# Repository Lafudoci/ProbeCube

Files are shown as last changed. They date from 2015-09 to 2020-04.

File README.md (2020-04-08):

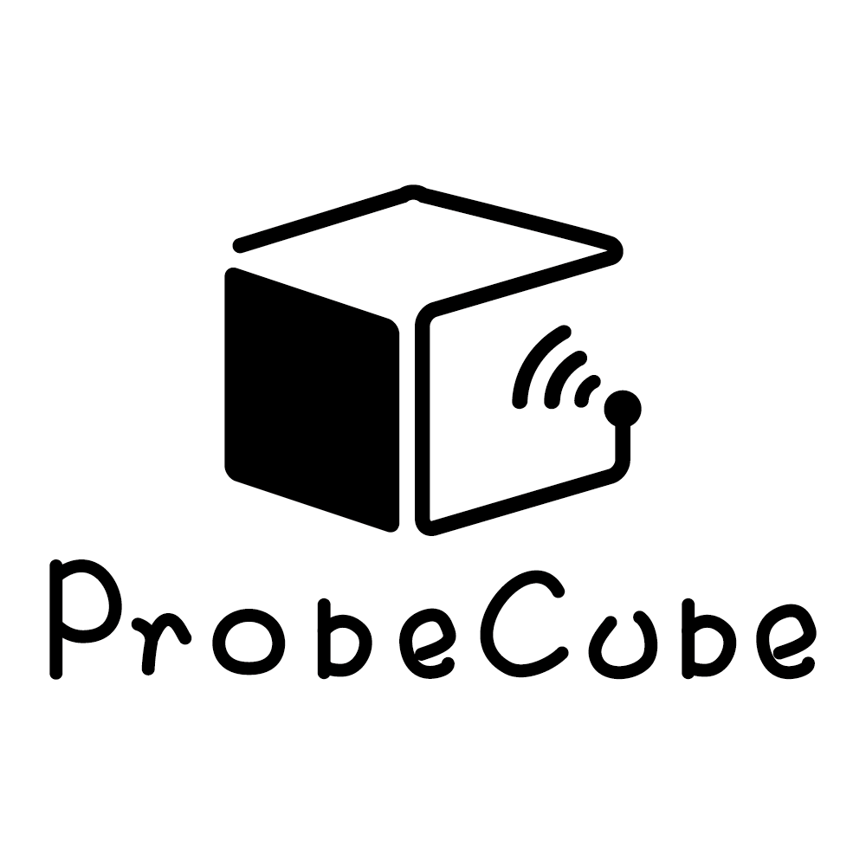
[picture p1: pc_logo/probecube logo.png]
 

## 專案簡介
ProbeCube是個基於開源硬體的物聯網專案，鼓勵大眾動手製作WiFi連網的機器來偵測空氣品質並組織共同的觀測地圖。

## 感測器開發方向原則
* 零件需容易取得
* 低組裝與操作門檻
* 相容於MIT開放原始碼授權

## 運作原理
空氣汙染 -> 感測器 -> Arduino(wifi) -> Thingspeak -> 觀測地圖

## 可相容的控制板
* Arduino NANO, UNO + Adafruit CC3000 wifi module
* Particle Photon

## 可相容的感測器
* 溫度/濕度 - DHT22
* 空氣中總揮發物質(VoCs) - FIGARO tgs2602
* 懸浮微粒PM2.5 - PMS3003(G3) 或 GP2Y1010AU0F
* 輻射劑量 - pockect gieger

## PCB設計附加規格
* 全腳位預留輸出排母
* I2C預留接座x2
* groove 預留接座x1

## 資料呈現方式
* 行動裝置: [Blynk app](http://www.blynk.cc/) (詳見範例)
* 網頁: Thingspeak, g0v零時空污觀測網 (詳見範例)

## 外殼
* 3D 列印外殼
* 自行挖洞加工收納盒 ( ex. 大創$39x2)

## 如何開始
1. 準備材料 (材料表)
2. 在PCB上焊接或使用麵包板連接各部元件組成ProbeCube
3. 註冊[Thingspeak](https://thingspeak.com/)帳號並設定上傳之頻道(channel)
4. 將程式碼依需要修改後編譯寫入ProbeCube
5. ProbeCube的資料將會上傳至Thingspeak
6. 到ProbeCube共同觀測地圖提交你的Thindspeak Channel ID分享資料(已併入g0v專案，請參考連結)

## 範例
* 麵包版接線示意

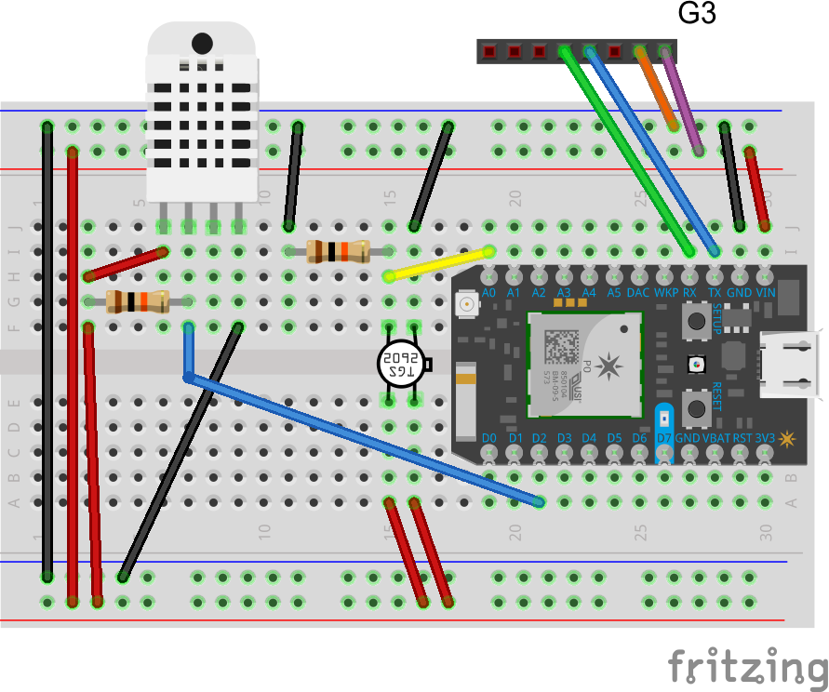
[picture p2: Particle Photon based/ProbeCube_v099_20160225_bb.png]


* 可洗PCB幫助縮小裝置體積

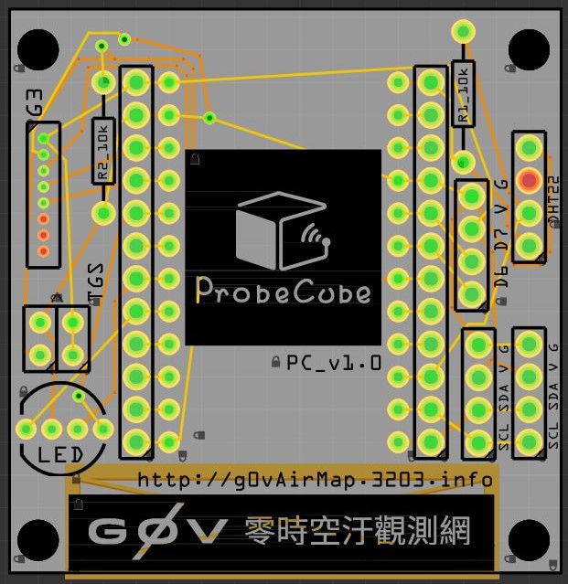
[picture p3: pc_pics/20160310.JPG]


* 由arduino uno為搭配已洗好PCB組裝後的ProbeCube  

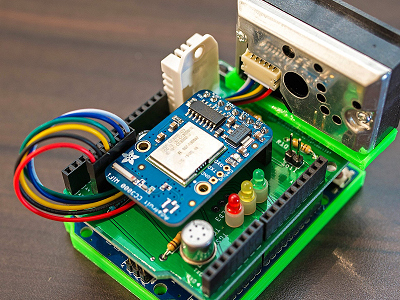
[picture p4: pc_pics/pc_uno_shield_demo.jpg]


* 用大創盒子挖洞加工成外殼  

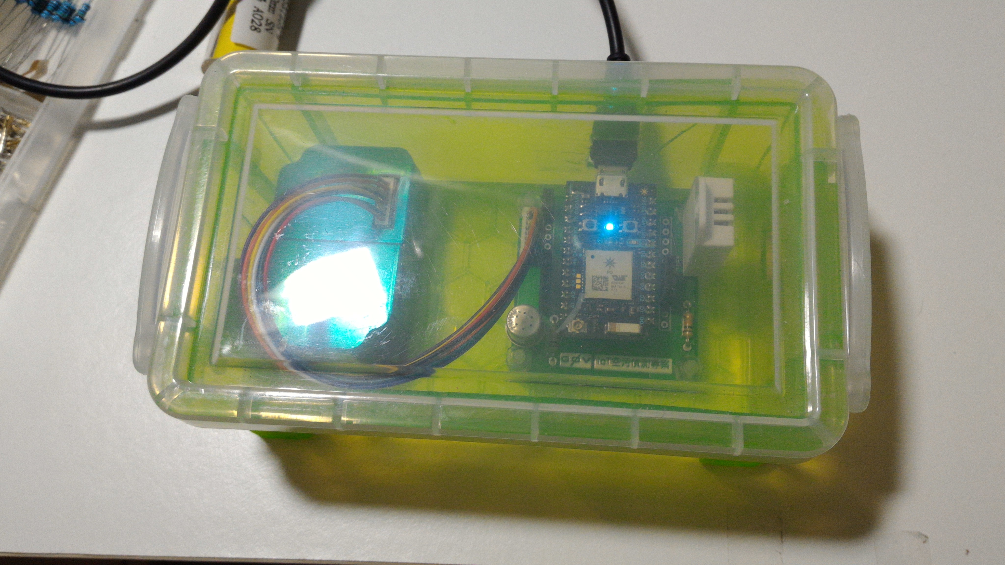
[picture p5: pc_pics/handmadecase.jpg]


* 由Particle Photon為主板組裝後的ProbeCube裝上3D print外殼搭配Blynk app的呈現

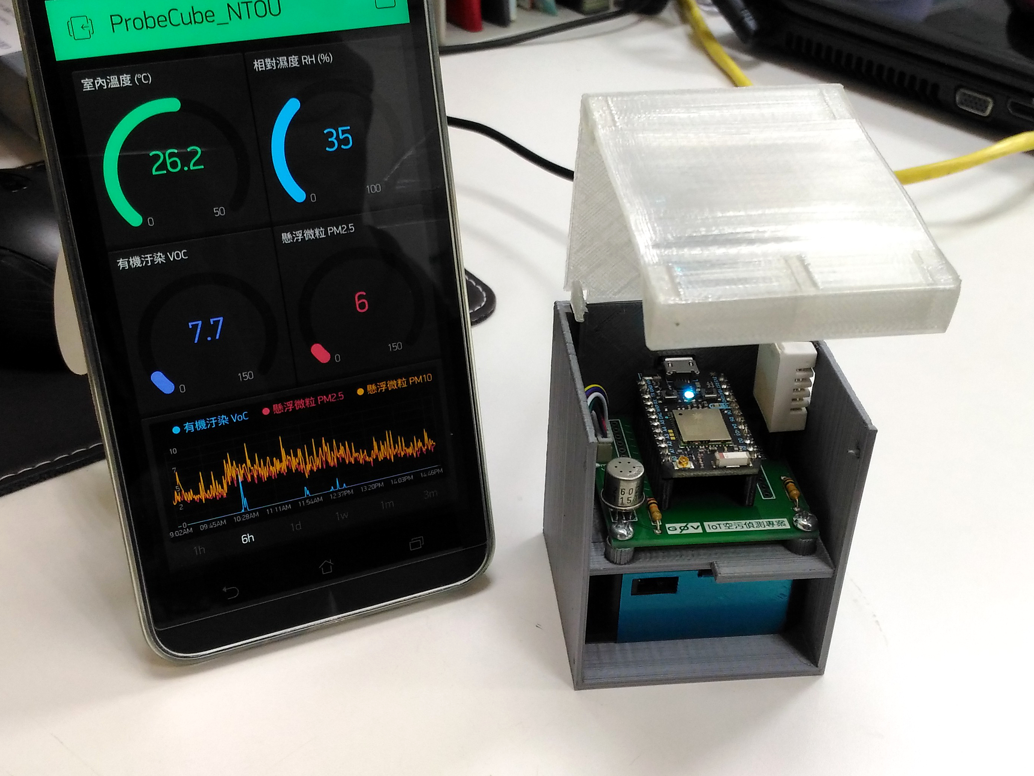
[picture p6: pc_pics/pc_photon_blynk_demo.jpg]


* 由Particle Photon為主板組裝後的ProbeCube裝上3D print外殼

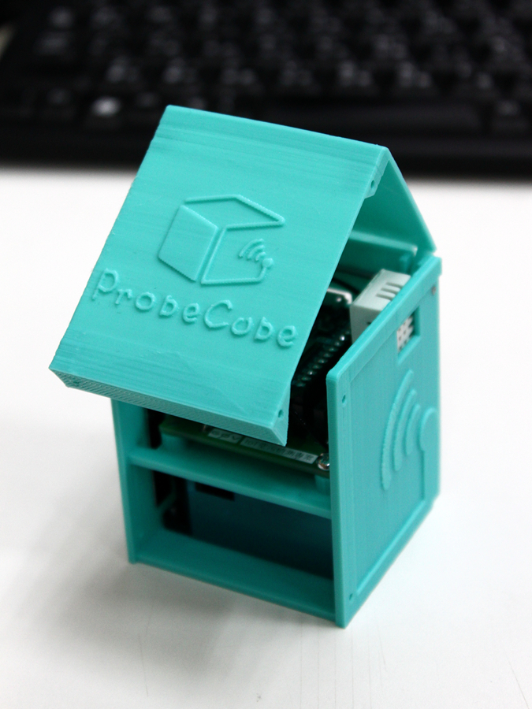
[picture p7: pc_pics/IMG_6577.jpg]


* [Thingspeak channel 範例](https://thingspeak.com/channels/26769) - 即時上傳的空氣觀測資料!

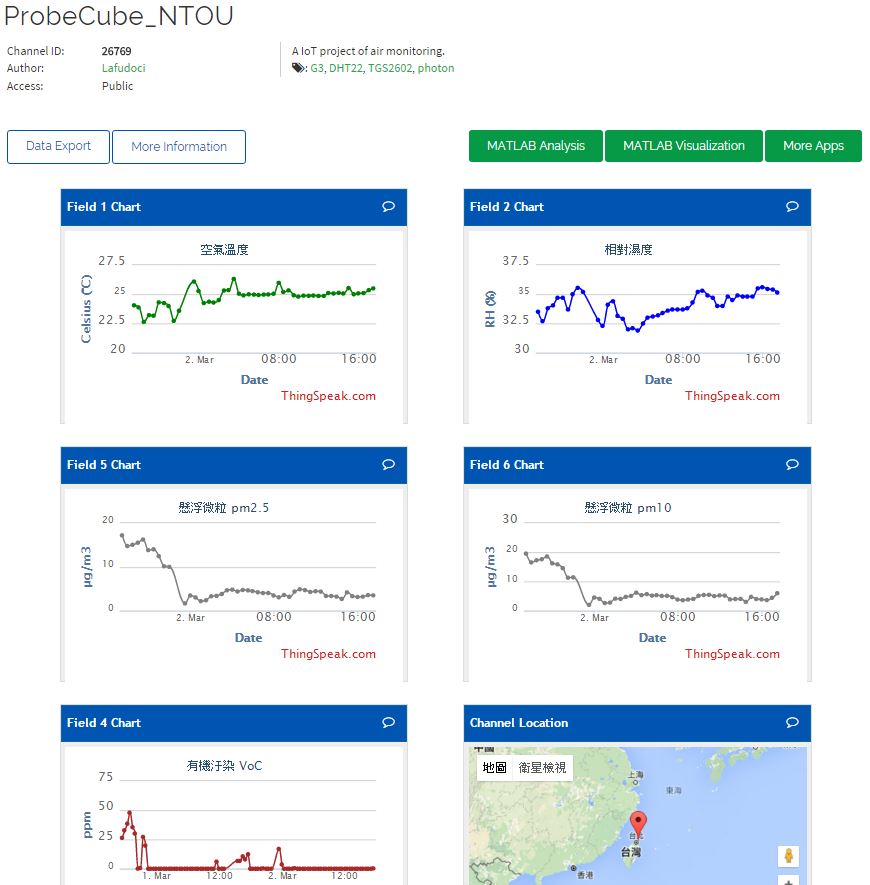
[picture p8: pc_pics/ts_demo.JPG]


* g0v零時空汙觀測網的即時呈現

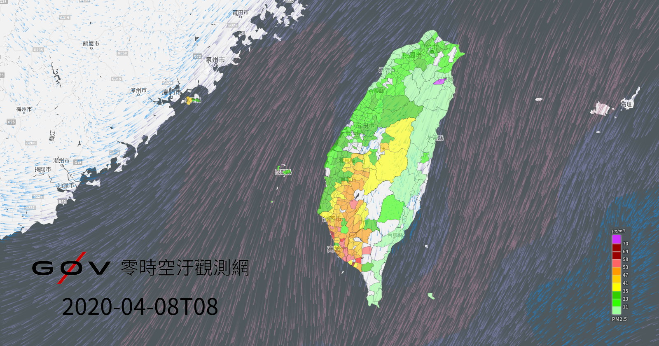
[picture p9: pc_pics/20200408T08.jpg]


## 連結

* [詳細組裝及設定步驟圖文](https://probecube.hackpad.com/-ProbeCube-fUI4k1BnZQ2)
* [g0v零時空汙觀測網專案](https://beta.hackfoldr.org/g0vairmap)

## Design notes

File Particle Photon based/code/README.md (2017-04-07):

Please include following libs at head of these codes in particle cloud IDE .<br>

#include <ProbeCube_blynk.h>

#include <ProbeCube_ThingSpeak.h>

#include <ProbeCube_DHT.h>

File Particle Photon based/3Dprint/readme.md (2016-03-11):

Print setting:

* Printer: FlashForge Creator
* Filement: PLA, 220c
* layer height: 0.2mm
* Number of shells: 2
* Minimum layer duration: 15s

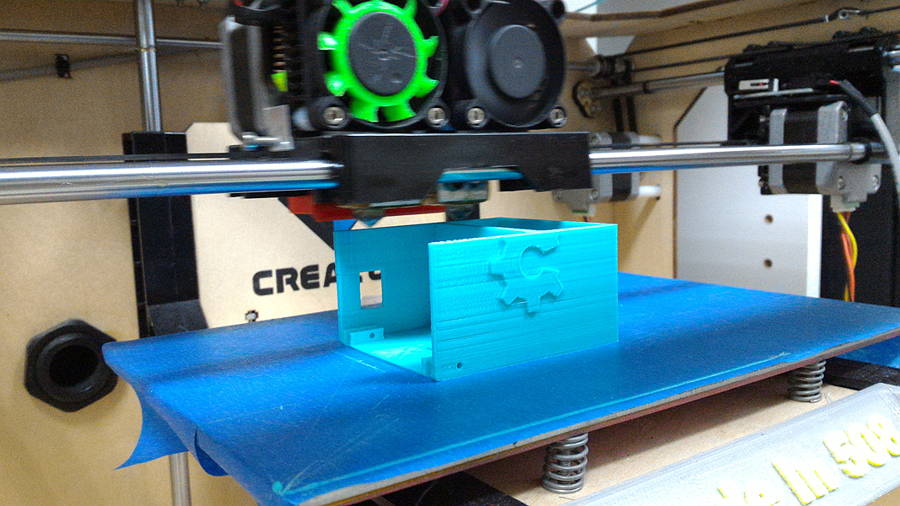
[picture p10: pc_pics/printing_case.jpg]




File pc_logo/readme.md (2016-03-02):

<br />本<span xmlns:dct="http://purl.org/dc/terms/" href="http://purl.org/dc/dcmitype/StillImage" rel="dct:type">著作</span>由<span xmlns:cc="http://creativecommons.org/ns#" property="cc:attributionName">ChiaLing Chung </span>製作，以<a rel="license" href="http://creativecommons.org/licenses/by-nc-nd/3.0/tw/">創用CC 姓名標示-非商業性-禁止改作 3.0 台灣 授權條款</a>釋出。

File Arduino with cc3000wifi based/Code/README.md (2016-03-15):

使用說明:<br>
1. 安裝ch341驅動程式<br>
2. 匯入liberies內zip檔案至arduino IDE<br>
3. 將對應版本程式碼(配有不同module的機種)複製貼上至arduino開發編輯器<br>
4. 修改程式碼中以下冒號內數值後即可上傳至arduino板子:<br>
    API write key<br>
    wifi帳號與密碼<br>
    GP2Y1010校正參數 (G3機種不必填)<br>
<br>
注意: 程式碼內包含WDT的重置方法，若使用arduinonano的板子建議[先刷optiboot的韌體]<br>
(http://lafudo.blogspot.tw/2015/02/arduino-nanoloaderoptibootwatch-dog.html)<br>
<br>
v0.98 changes:<br>
調換宣告結構順序方便更改參數<br>
更改計時的方式由delay改為精準millis計時觸發上傳動作<br>
更改等待DHCP的方式，若5秒內無法取得IP則重新啟動wifi晶片<br>
移除警告燈號的功能<br>
<br>
v0.99b0223 changes:<br>
新增DHCP冷卻時間機制避免某些路由器issue<br>
<br>
v0.99b0224 changes:<br>
取得thingspeak ip的動作改為僅在開機要求一次<br>
http get後讀回thingspeak的回傳字串<br>
加入connect close<br>

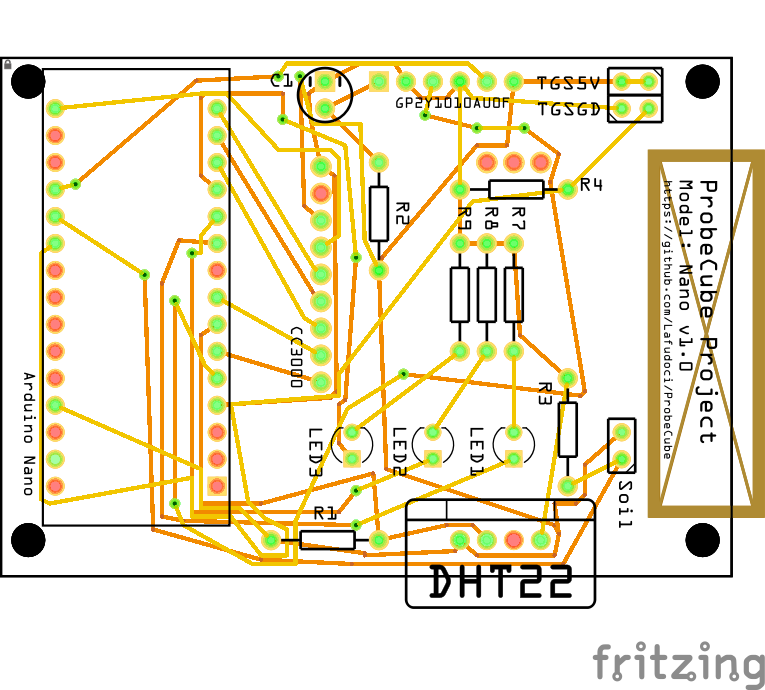
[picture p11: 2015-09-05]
Arduino with cc3000wifi based/Fritzing_sketch/ProbeCube_Nano/ProbeCube_nano_v1_pcb.png

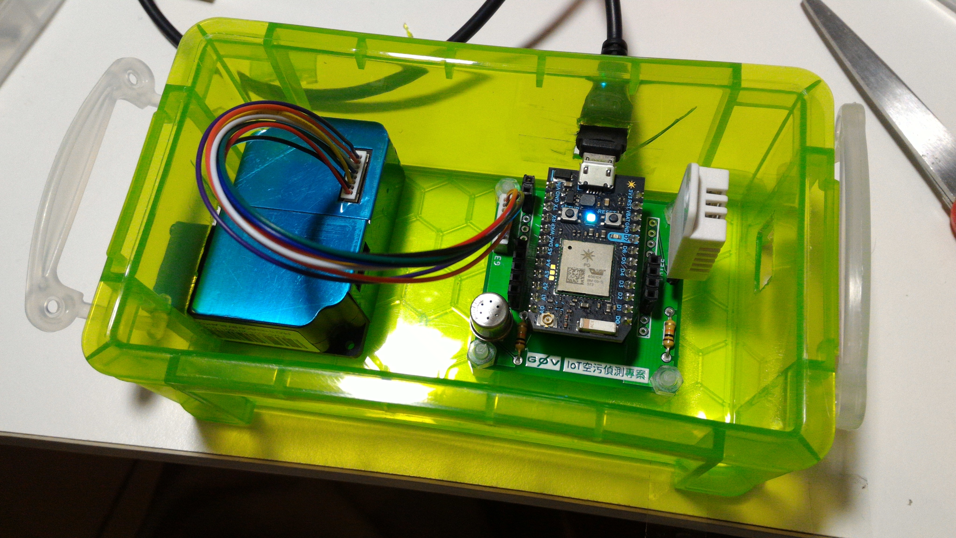
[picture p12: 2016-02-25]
pc_pics/2016-02-25_PC.jpg

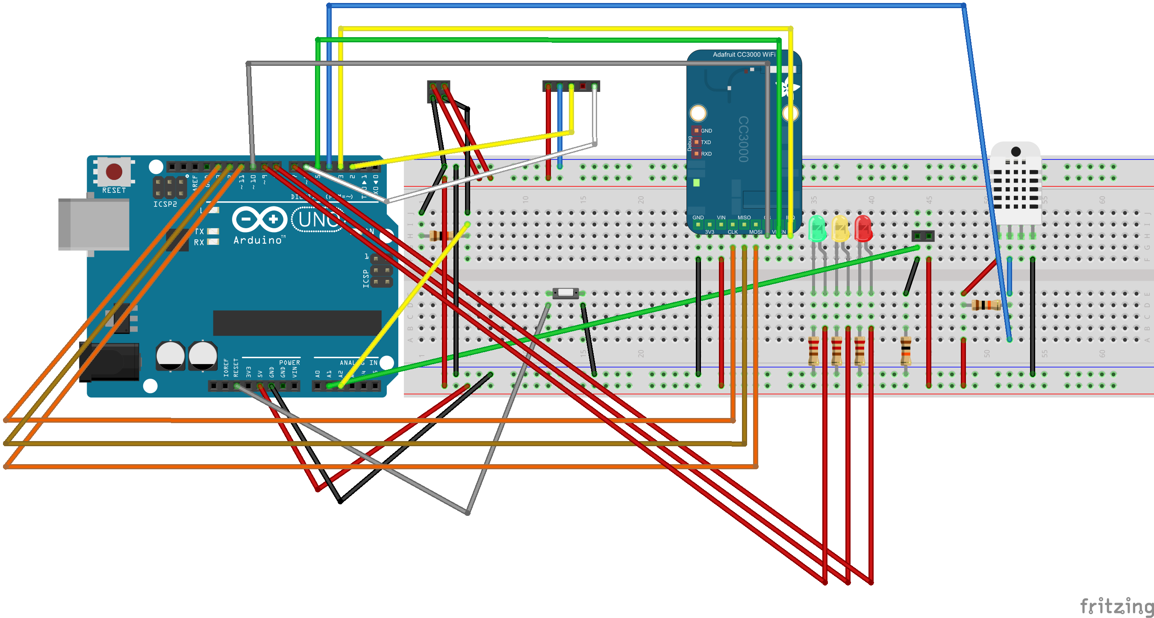
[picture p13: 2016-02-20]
Arduino with cc3000wifi based/Code/Gieger_module/Fritzing_sketch/ProbeCube_gieger_bb.png

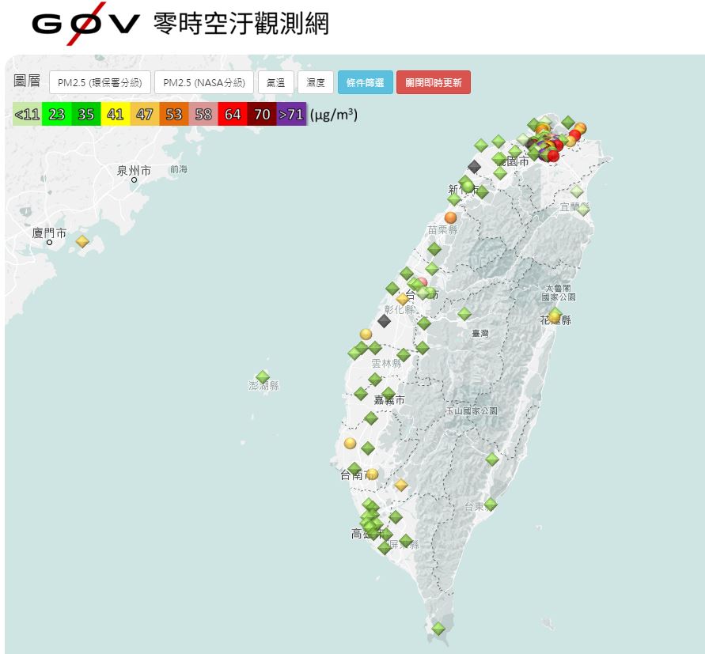
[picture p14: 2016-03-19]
pc_pics/g0vairmap.JPG

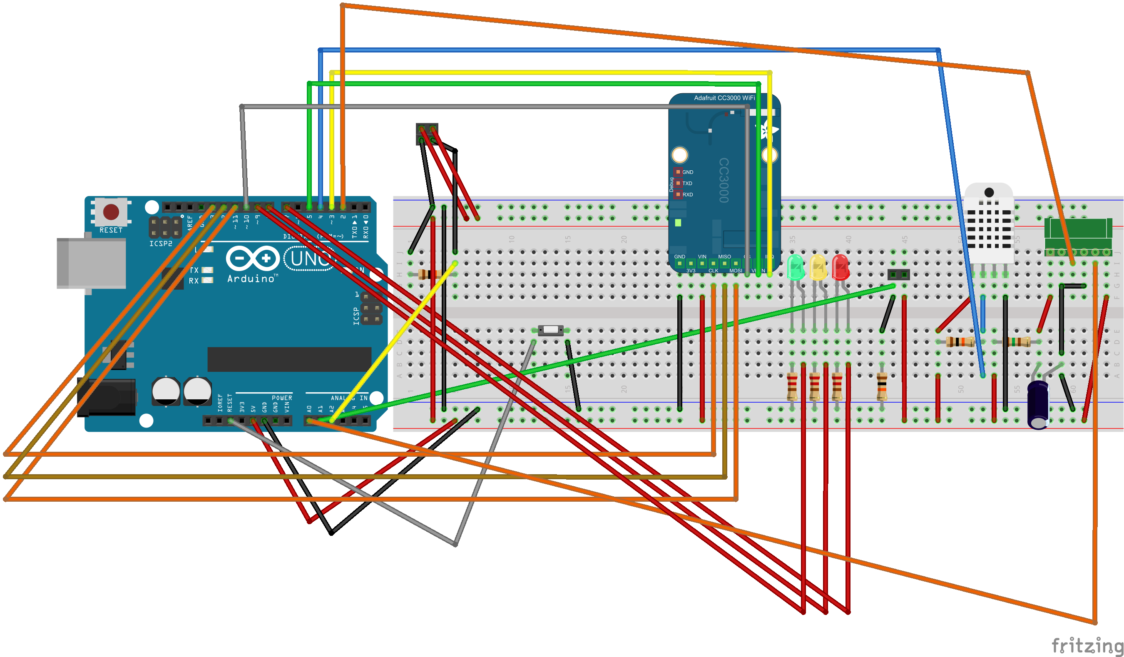
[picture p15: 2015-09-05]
Arduino with cc3000wifi based/Fritzing_sketch/ProbeCube_Uno/ProbeCube_shield_v1_bb.png

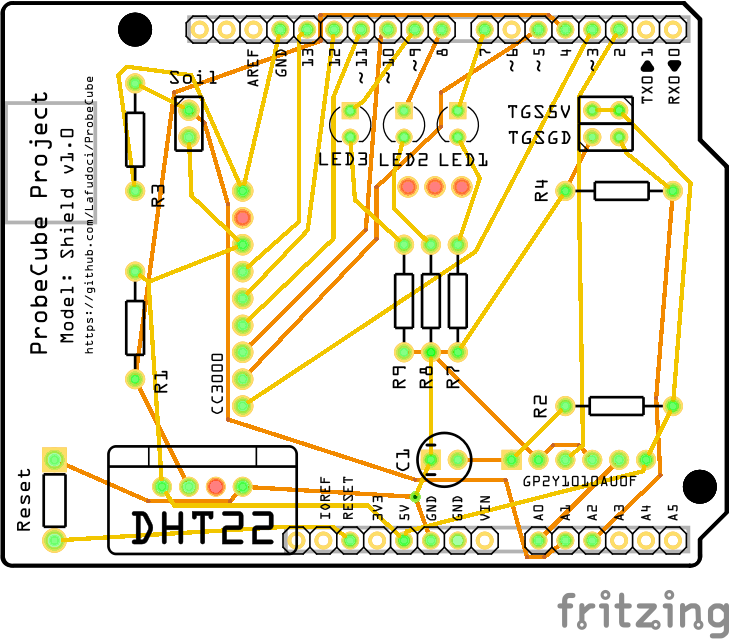
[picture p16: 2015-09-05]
Arduino with cc3000wifi based/Fritzing_sketch/ProbeCube_Uno/ProbeCube_shield_v1_pcb.png

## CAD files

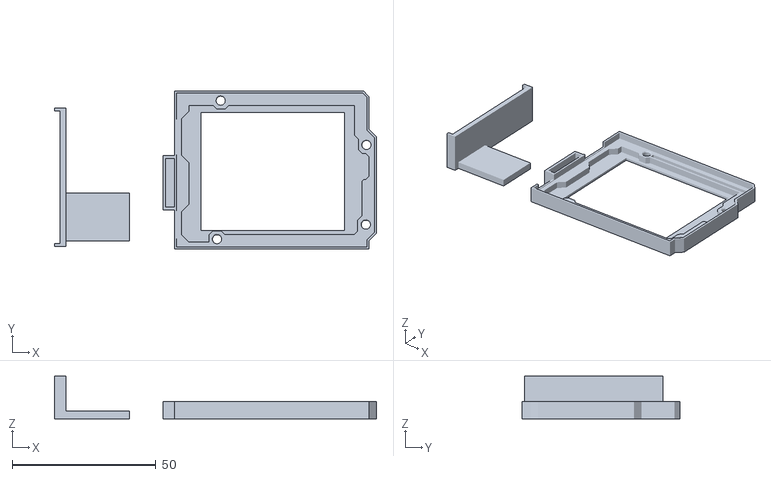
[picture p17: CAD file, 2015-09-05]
Arduino with cc3000wifi based/3Dprint_part/ProbeCube_shiled_bumper_v1.stl
112.2 x 55.2 x 15.0

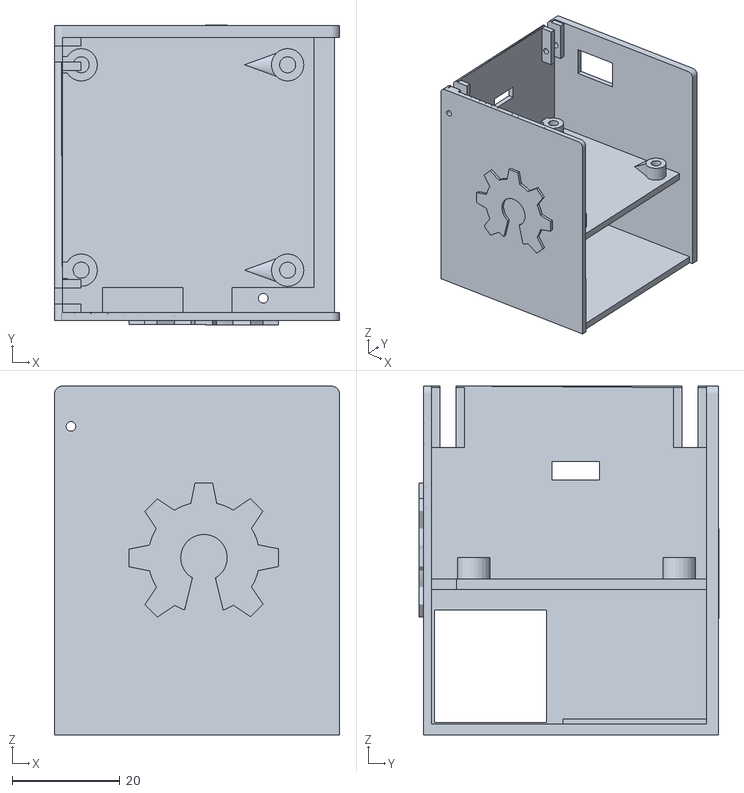
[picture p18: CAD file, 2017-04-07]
Particle Photon based/3Dprint/pc100open_r2_base_fixed.stl
53.0 x 55.7 x 64.8

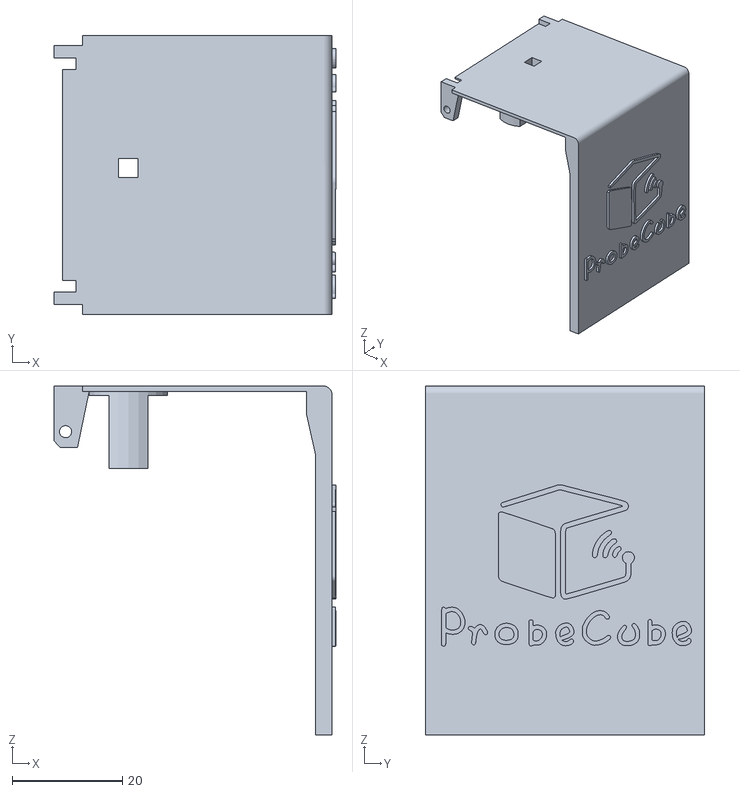
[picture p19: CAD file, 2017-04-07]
Particle Photon based/3Dprint/pc100open_r2_top_fixed.stl
51.2 x 50.6 x 63.4

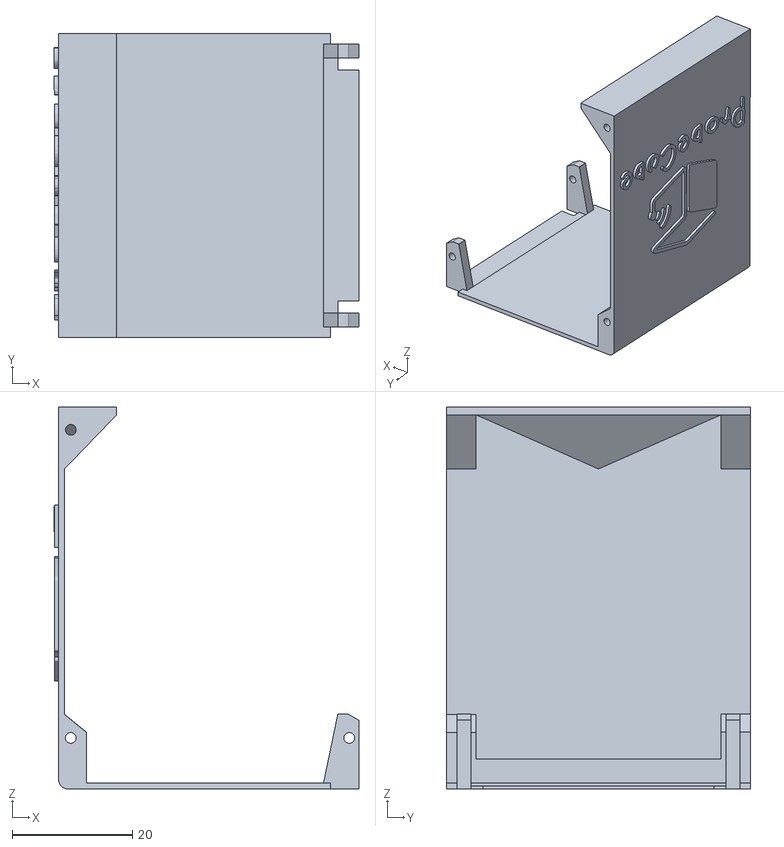
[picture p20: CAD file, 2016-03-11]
Particle Photon based/3Dprint/pc099open_r4_top_fixed.stl
50.7 x 50.6 x 63.6

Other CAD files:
Particle Photon based/3Dprint/pc099open_r4_base_fixed.stl

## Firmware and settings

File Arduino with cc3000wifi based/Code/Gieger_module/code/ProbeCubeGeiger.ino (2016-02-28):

//////////////////////////////////////////////////
// Modified by Lafudoci based on Radiation-Watch.org
// Released under MIT License.
//////////////////////////////////////////////////
///　Digital I/O PIN Settings　///
int signPin = 2; //Radiation Pulse (Yellow)
int noisePin = 6; //Vibration Noise Pulse (White)
//VCC 5V (Red)
//GND (Blue)
////////////////////////////////

///　Digital I/O PIN Settings　///
int signPin = 2; //Radiation Pulse (Yellow)
int noisePin = 6; //Vibration Noise Pulse (White)
//VCC 5V (Red)
//GND (Blue)
////////////////////////////////

//thingspeak設定變數
String writeAPIKey =    "ZMQP9SDP20PJXXXX";  //填入thingspeak write API key ***必填
//CC3000無線網路設定變數
#define WLAN_SSID       "3203BIGDATA"     //填入無線網路名稱  ***必填
#define WLAN_PASS       "3203BIGDATA"     //填入無線網路密碼  ***必填

//版本號
#define VERSION "0.98_Geiger"
//cc3000設定
#define WLAN_SECURITY   WLAN_SEC_WPA2     //無線網路加密方式
#include <Wire.h>
#include <Adafruit_CC3000.h>
#include <ccspi.h>
#include <SPI.h>
#include <avr/wdt.h>
#define ADAFRUIT_CC3000_IRQ   3
#define ADAFRUIT_CC3000_VBAT  5
#define ADAFRUIT_CC3000_CS    10
Adafruit_CC3000 cc3000 = Adafruit_CC3000(ADAFRUIT_CC3000_CS, ADAFRUIT_CC3000_IRQ, ADAFRUIT_CC3000_VBAT, SPI_CLOCK_DIV2);
//指定指示燈腳位
#define red_led     7
#define yellow_led  8
#define green_led   9
//thingspeak上傳設定
String thingSpeakAddress = "http://api.thingspeak.com/update?";
//#define Thingspeak_INTERVAL_seconds 300

//SENSOR設定
//溫溼度
#include <DHT.h>
#define DHTPIN 4 //指定要量測的腳位為D4
#define DHTTYPE DHT22 //指定溫溼度感測器種類為DHT22
DHT dht(DHTPIN, DHTTYPE);
//溫濕度校正變數設定
#define Compensator_tem 0
#define Compensator_hum 0
//===========================
//土壤濕度
#define soilSensor 1 //指定要量測的腳位為A1
//有機汙染
#define gasSensor 2 //指定要量測的腳位為A2

const double alpha = 53.032; // cpm = uSv x alpha
float usv = 0;
//char sensor_usv[6];

void setup(void)
{
  //Serial setup
  //9600bps
  Serial.begin(9600);

  //PIN setting for Radiation Pulse
  pinMode(signPin, INPUT);
  digitalWrite(signPin, HIGH);

  //PIN setting for Noise Pulse
  pinMode(noisePin, INPUT);
  digitalWrite(noisePin, HIGH);

  Serial.println(F("ProbeCube is starting"));
  Serial.print(F("code version: "));
  Serial.println(VERSION);

  //LED們初始化
  pinMode(red_led, OUTPUT);
  pinMode(yellow_led, OUTPUT);
  pinMode(green_led, OUTPUT);

  do {
    LED_start();
    LED_check();
    Serial.print(F("Initializing WiFi chip..."));  //CC3000初始化
    if (!cc3000.begin())
    {
      Serial.println(F("Couldn't begin()! Check your wiring?"));
      LED_error();
      while (1);
    }

    Serial.println(F("\nDeleting old connection profiles"));
    if (!cc3000.deleteProfiles()) {
      Serial.println(F("Failed!"));
      LED_error();
      while (1);
    }
    // Connect to WiFi network
    Serial.print(F("Connecting to WiFi network ..."));
    cc3000.connectToAP(WLAN_SSID, WLAN_PASS, WLAN_SECURITY);
    Serial.println(F("done!"));

    // Wait for DHCP to complete
    Serial.println(F("Request DHCP ..."));
    LED_error();
    delay(5000);
  }
  while (!cc3000.checkDHCP());

  Serial.println(F("Connection is established!"));

  LED_ok();

  delay(500);       //延遲500ms


}

void loop(void)     //循環函數區域
{
  //計算輻射量
  String sensor_usv =  String(measure_radi(), 3);
  Serial.println("sensor_usv:");
  Serial.println(sensor_usv);
  //讀取溫溼度
  float sensor_tem = measure_tem();
  float sensor_hum = measure_hum();

  //讀取土壤濕度
  int sensor_soil = measure_soil();

  //讀取有機氣體汙染
  float sensor_voc = measure_voc();

  //啟動看門狗
  wdt_enable (WDTO_8S);
  // 取得 thingspeak IP
  uint32_t ip = 0;
  Serial.print(F("Finding api.thingspeak.com -> "));
  while  (ip  ==  0)  {
    if  (!  cc3000.getHostByName("api.thingspeak.com", &ip))  {
      Serial.println(F("Couldn't resolve!"));
      while (1) {
      }
    }
    delay(500);
  }
  cc3000.printIPdotsRev(ip);
  Serial.println(F(""));
  Adafruit_CC3000_Client client = cc3000.connectTCP(ip, 80); //定義client

  wdt_reset ();

  //使用http get送出數據
  client.fastrprint(F("GET "));
  client.print(thingSpeakAddress);
  client.fastrprint(F("api_key="));
  client.print(writeAPIKey);
  Serial.println (F("Sending data:")); //顯示上傳的數據
  Serial.print(F("GET "));
  Serial.print(thingSpeakAddress);
  Serial.println(writeAPIKey);
  LED_send();
  wdt_reset ();
  client.fastrprint(F("&field1="));
  client.print(sensor_tem);
  LED_send();
  client.fastrprint(F("&field2="));
  client.print(sensor_hum);
  LED_send();
  client.fastrprint(F("&field3="));
  client.print(sensor_usv);
  LED_send();
  client.fastrprint(F("&field4="));
  client.print(sensor_voc);
  LED_send();
  //  client.fastrprint(F("&field5="));
  //  client.print(sensor_usv);
  LED_send();
  client.fastrprint(F("\r\n"));
  wdt_reset ();
  wdt_disable();

  Serial.print(F("&field1="));
  Serial.print(sensor_tem);
  Serial.print(F("&field2="));
  Serial.print(sensor_hum);
  Serial.print(F("&field3="));
  Serial.print(sensor_usv);
  Serial.print(F("&field4="));
  Serial.print(sensor_voc);
  //  Serial.print(F("&field5="));
  //  Serial.print(sensor_usv);
  Serial.print(F("\r\n"));

  Serial.println(F("Data has been sent successfully, waiting for next update..."));
  Serial.println();
}


float measure_tem() {
  return (dht.readTemperature() + Compensator_tem);
}

float measure_hum() {
  return (dht.readHumidity() + Compensator_hum);
}

float measure_soil() {
  return analogRead(soilSensor);
}

float measure_radi() {

  //CSV-formatting for serial output (substitute , for _)
  Serial.println(F("hour[h]_sec[s]_count_cpm_uSv/h_uSv/hError"));

  int index = 0; //Number of loops
  char msg[256] = ""; //Message buffer for serial output
  int signCount = 0; //Counter for Radiation Pulse
  int noiseCount = 0; //Counter for Noise Pulse

  int sON = 0; //Lock flag for Radiation Pulse
  int nON = 0; //Lock flag for Noise Puls

  double cpm = 0; //Count rate [cpm] of current
  double cpmHistory[50]; //History of count rates
  int cpmIndex = 0; //Position of current count rate on cpmHistory[]
  int cpmIndexPrev = 0; //Flag to prevent duplicative counting

  //Timing Settings for Loop Interval
  int prevTime = 0;
  int currTime = 0;

  int totalSec = 0; //Elapsed time of measurement [sec]
  int totalHour = 0; //Elapsed time of measurement [hour]

  //Time settings for CPM calcuaration
  int cpmTimeMSec = 0;
  int cpmTimeSec = 0;
  int cpmTimeMin = 0;

  //String buffers of float values for serial output
  char cpmBuff[20];
  char uSvBuff[20];
  char uSvdBuff[20];

  //Initialize cpmHistory[]
  for (int i = 0; i < 50; i++ )
  {
    cpmHistory[i] = 0;
  }

  //Get start time of a loop
  prevTime = millis();

  while ( totalSec < 300) {
    // Raw data of Radiation Pulse: Not-detected -> High, Detected -> Low
    // 輻射測量: 無檢測到->high, 檢測到->low
    int sign = digitalRead(signPin);

    // Raw data of Noise Pulse: Not-detected -> Low, Detected -> High
    // 雜訊測量: 無檢測到->low, 檢測到->high
    int noise = digitalRead(noisePin);

    //Radiation Pulse normally keeps low for about 100[usec]
    //輻射波訊號通常持續100usec
    //Deactivate Radiation Pulse counting for a while
    //若此迴圈偵測到(sign==0)且上一個迴圈也偵測到(sON==1)則不計數
    if (sign == 0 && sON == 0)
    {
      sON = 1;
      signCount++;
    } else if (sign == 1 && sON == 1) { //直到此次測量無偵測則開啟下一次計數
      sON = 0;
    }

    //Noise Pulse normally keeps high for about 100[usec]
    //背景雜訊通常持續100usec
    //Deactivate Noise Pulse counting for a while
    //若此迴圈偵測到(noise==1)且上一個迴圈也偵測到(nON==1)則不計數
    //Noise Pulse normally keeps high for about 100[usec]
    if (noise == 1 && nON == 0)
    { //Deactivate Noise Pulse counting for a while
      nON = 1;
      noiseCount++;
    } else if (noise == 0 && nON == 1) { //直到此次測量無偵測則開啟下一次計數
      nON = 0;
    }

    //Output readings to serial port, after 10000 loops
    //測量10000次後輸出到serial顯示，循環週期在arduino Nano(ATmega328)上大約為160-170毫秒
    if (index == 10000) //About 160-170 msec in Arduino Nano(ATmega328)
    {
      //      Serial.println("noiseCount:");
      //      Serial.println(noiseCount);
      //Get current time
      currTime = millis();

      //No noise detected in 10000 loops
      //若10000循環無雜訊則進行計算
      if (noiseCount == 0)
      {
        //Shift an array for counting log for each 6 sec.
        if ( totalSec % 6 == 0 && cpmIndexPrev != totalSec)
        {
          cpmIndexPrev = totalSec;
          cpmIndex++;

          if (cpmIndex >= 200)
          {
            cpmIndex = 0;
          }

          if (cpmHistory[cpmIndex] > 0)
          {
            cpm -= cpmHistory[cpmIndex];
          }
          cpmHistory[cpmIndex] = 0;
        }

        //Store count log
        cpmHistory[cpmIndex] += signCount;
        //Add number of counts
        cpm += signCount;

        //Get ready time for 10000 loops
        cpmTimeMSec += abs(currTime - prevTime);
        //Transform from msec. to sec. (to prevent overflow)
        if (cpmTimeMSec >= 1000)
        {
          cpmTimeMSec -= 1000;
          //Add measurement time to calcurate cpm readings (max=20min.)
          if ( cpmTimeSec >= 20 * 60 )
          {
            cpmTimeSec = 20 * 60;
          } else {
            cpmTimeSec++;
          }

          //Total measurement time
          totalSec++;
          //Transform from sec. to hour. (to prevent overflow)
          if (totalSec >= 3600)
          {
            totalSec -= 3600;
            totalHour++;
          }
        }

        //Elapsed time of measurement (max=20min.)
        double min = cpmTimeSec / 60.0;
        if (min != 0)
        {
          //Calculate cpm, uSv/h and error of uSv/h
          dtostrf(cpm / min, -1, 3, cpmBuff);
          dtostrf(cpm / min / alpha, -1, 3, uSvBuff);
          dtostrf(sqrt(cpm) / min / alpha, -1, 3, uSvdBuff);
        } else {
          //Devision by zero
          dtostrf(0, -1, 3, cpmBuff);
          dtostrf(0, -1, 3, uSvBuff);
          dtostrf(0, -1, 3, uSvdBuff);
        }

        //Create message for serial port
        sprintf(msg, "%d,%d.%03d,%d,%s,%s,%s",
                totalHour, totalSec,
                cpmTimeMSec,
                signCount,
                cpmBuff,
                uSvBuff,
                uSvdBuff
               );
        usv = cpm / min / alpha;

        //Send message to serial port
        Serial.print(msg);
        Serial.print(F(" -> usv: "));
        Serial.println(usv, 3);
      } else {
        Serial.println(F("high noise level"));
      }

      //Initialization for next 10000 loops
      prevTime = currTime;
      signCount = 0;
      noiseCount = 0;
      index = 0;
    }
    index++;
  }
  return usv;
}

float measure_voc() {
  float tgsADVcalib_tm = analogRead(gasSensor) * (-0.0256 * dht.readTemperature() + 1.535); //將ADV做溫度補償
  float tgsADVcalib_tm_hm = tgsADVcalib_tm * (-0.0029 * dht.readHumidity() + 1.1938); //將ADV做濕度補償
  float voc = (tgsADVcalib_tm_hm - 113.87) / 10.497; //將ADV換算成ppm濃度
  if (voc < 0) {
    voc = 0;   //將負數的讀值歸零
  }
  return voc;
}


void LED_start()
{
  digitalWrite(red_led, HIGH);
  digitalWrite(yellow_led, HIGH);
  digitalWrite(green_led, HIGH);
  delay(1000);
  digitalWrite(red_led, LOW);
  digitalWrite(yellow_led, LOW);
  digitalWrite(green_led, LOW);
  delay(500);
  digitalWrite(red_led, HIGH);
  digitalWrite(yellow_led, HIGH);
  digitalWrite(green_led, HIGH);
  delay(1000);
  digitalWrite(red_led, LOW);
  digitalWrite(yellow_led, LOW);
  digitalWrite(green_led, LOW);
}

void LED_check()
{
  digitalWrite(red_led, HIGH);
  digitalWrite(yellow_led, HIGH);
  digitalWrite(green_led, LOW);
}

void LED_wait()
{
  digitalWrite(red_led, LOW);
  digitalWrite(yellow_led, HIGH);
  digitalWrite(green_led, LOW);
}

void LED_error()
{
  digitalWrite(red_led, HIGH);
  digitalWrite(yellow_led, LOW);
  digitalWrite(green_led, LOW);
}

void LED_ok()
{
  digitalWrite(red_led, LOW);
  digitalWrite(yellow_led, LOW);
  digitalWrite(green_led, HIGH);
}

void LED_send()
{
  digitalWrite(green_led, LOW);
  delay(100);
  digitalWrite(green_led, HIGH);
}

void LED_warning_yellow()
{
  for (int i = 0; i <= 270; i++) {
    digitalWrite(yellow_led, HIGH);
    delay(100);
    digitalWrite(yellow_led, LOW);
    delay(100);
  }
}

void LED_warning_red()
{
  for (int i = 0; i <= 270; i++) {
    digitalWrite(red_led, HIGH);
    digitalWrite(yellow_led, HIGH);
    delay(100);
    digitalWrite(red_led, LOW);
    digitalWrite(yellow_led, LOW);
    delay(100);
  }
}

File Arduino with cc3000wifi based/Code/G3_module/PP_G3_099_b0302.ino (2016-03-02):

//thingspeak設定變數
String writeAPIKey =    "H9G82IFDUQFLXXXX";  //填入thingspeak write API key ***必填
//CC3000無線網路設定變數
#define WLAN_SSID       "3203BIGDATA"     //填入無線網路名稱  ***必填
#define WLAN_PASS       "3203BIGDATA"     //填入無線網路密碼  ***必填

//版本號
#define VERSION "G3099b0302"
//cc3000設定
#define WLAN_SECURITY   WLAN_SEC_WPA2     //無線網路加密方式
#include <Wire.h>
#include <Adafruit_CC3000.h>
#include <ccspi.h>
#include <SPI.h>
#include <avr/wdt.h>
#define ADAFRUIT_CC3000_IRQ   3
#define ADAFRUIT_CC3000_VBAT  5
#define ADAFRUIT_CC3000_CS    10
Adafruit_CC3000 cc3000 = Adafruit_CC3000(ADAFRUIT_CC3000_CS, ADAFRUIT_CC3000_IRQ, ADAFRUIT_CC3000_VBAT, SPI_CLOCK_DIVIDER);
uint32_t ip = 0;
uint32_t DHCPwait;
uint32_t checkDHCP;
uint32_t IPwait;
//指定指示燈腳位
#define green_led   9
#define yellow_led  8
//thingspeak上傳設定
String thingSpeakAddress = "http://api.thingspeak.com/update?";
#define Thingspeak_INTERVAL 60000
unsigned long currentMillis = 0;
unsigned long previousUpdateMillis = 0;
boolean firstRun = true;
boolean RunOnce = false;
boolean needUpdate;

//SENSOR設定
//溫溼度
#include <DHT.h>
#define DHTPIN 4 //指定要量測的腳位為D4
#define DHTTYPE DHT22 //指定溫溼度感測器種類為DHT22
float dht_tem = 0;
float dht_hum = 0;
float measure_tem = 0;
float measure_hum = 0;
#define MIN_TEMPERATURE -30
#define MAX_TEMPERATURE 99
#define MIN_HUMIDITY 0
#define MAX_HUMIDITY 100
DHT dht(DHTPIN, DHTTYPE);
//溫濕度校正變數設定
#define Compensator_tem -7
#define Compensator_hum 17
//===========================
//土壤濕度
#define soilSensor 1 //指定要量測的腳位為A1
//有機汙染
#define gasSensor 2 //指定要量測的腳位為A2
//懸浮微粒
#include <SoftwareSerial.h>
SoftwareSerial Serial_g3(2 , 6); // RX, TX
long  pmcf10 = 0;
long  pmcf25 = 0;
long  pmcf100 = 0;
long  pmat10 = 0;
long  pmat25 = 0;
long  pmat100 = 0;
//char buf[50];
#define G3SetPin 7
//****************************************************************************
void setup(void)
{
  //指定通訊視窗115200
  Serial.begin(115200);

  //g3
  Serial_g3.begin(9600);

  Serial.println("ProbeCube is starting");
  Serial.print("code version: ");
  Serial.println(VERSION);

  //LED們初始化
  pinMode(green_led, OUTPUT);
  pinMode(yellow_led, OUTPUT);
  pinMode(G3SetPin, OUTPUT);
  digitalWrite(G3SetPin, LOW); //關閉G3

  do {
    DHCPwait = 0;
    checkDHCP = 1;
    IPwait = 0;

    LED_start();
    LED_check();
    //    displayDriverMode();

    Serial.println(F("Initialising the CC3000 wifi ..."));
    if (!cc3000.begin()) {
      Serial.println(F("Unable to initialise the CC3000! Check your wiring?"));
      for (;;);
    }

    uint16_t firmware = checkFirmwareVersion();
    if (firmware < 0x113) {
      Serial.println(F("Wrong firmware version!"));
      for (;;);
    }

    displayMACAddress();

    Serial.println(F("Deleting old connection profiles"));
    if (!cc3000.deleteProfiles()) {
      Serial.println(F("Failed!"));
      while (1);
    }

    /* Attempt to connect to an access point */
    char *ssid = WLAN_SSID;             /* Max 32 chars */
    Serial.print(F("Attempting to connect to ")); Serial.println(ssid);

    /* NOTE: Secure connections are not available in 'Tiny' mode! */
    if (!cc3000.connectToAP(WLAN_SSID, WLAN_PASS, WLAN_SECURITY)) {
      Serial.println(F("Failed!"));
      while (1);
    }

    Serial.println(F("Connected!"));

    /* Wait for DHCP to complete */
    Serial.print(F("Request DHCP...."));
    while (!cc3000.checkDHCP()) {
      if ( DHCPwait > 600) {
        checkDHCP = 0;
        Serial.println(F("failed..retry after 3 mins"));
        LED_error();
        delay(30000);
        break;
      }
      LED_wait();
      delay(100);
      DHCPwait++;
    }


    while (!displayConnectionDetails()) {
      if ( IPwait > 30) {
        checkDHCP = 0;
        Serial.println(F("Connection failed.."));
        LED_error();
        break;
      }
      delay(1000);
      IPwait++;
    }
  } while (checkDHCP != 1);
  Serial.println(F("Connection is established!"));

  wdt_enable (WDTO_8S);
  // 取得 thingspeak IP
  Serial.print(F("Finding api.thingspeak.com -> "));
  while  (ip  ==  0)  {
    if  (!  cc3000.getHostByName("api.thingspeak.com", &ip))  {
      Serial.println(F("Couldn't resolve!"));
      while (1) {
      }
    }
    delay(500);
  }
  wdt_disable();
  Serial.print(F("("));
  cc3000.printIPdotsRev(ip);
  Serial.println(F(")"));

  LED_ok();

  delay(500);       //延遲500ms

}

void loop(void)     //循環函數區域
{
  currentMillis = millis(); //記錄當下時間
  if (currentMillis - previousUpdateMillis >= Thingspeak_INTERVAL) { //判斷是否需要上傳
    needUpdate = true;
  }
  else {
    needUpdate = false;
  }
  if (firstRun) { //若為第一次執行則強迫判斷為需要更新
    needUpdate = true;
    firstRun = false;
  }
  if (needUpdate) { //若判斷為需要更新則開始測量&上傳

    Serial.println(F("Starting to monitor the air....."));
    previousUpdateMillis = currentMillis;

    //讀取溫溼度
    measure_dht();
    float sensor_tem = measure_tem;
    Serial.println(F("Tem OK!"));
    float sensor_hum = measure_hum;
    Serial.println(F("Hum OK!"));

    //讀取土壤濕度
    int sensor_soil = measure_soil();
    Serial.println(F("soil OK!"));

    //讀取有機氣體汙染
    float sensor_voc = measure_voc();
    Serial.println(F("voc OK!"));
    //讀取灰塵感測
    measure_dust();
    int sensor_dust25 = pmat25;
    int sensor_dust100 = pmat100;


    Serial.println(F("Detection is finished"));
    Serial.println(F("====================="));
    Serial.print(F("Tm:"));
    Serial.print(sensor_tem);
    Serial.println(F("C"));
    Serial.print(F("Hm:"));
    Serial.print(sensor_hum);
    Serial.println(F("%"));
    Serial.print(F("Soil:"));
    Serial.print(sensor_soil);
    Serial.println(F("ohm"));
    Serial.print(F("VOCs:"));
    Serial.print(sensor_voc);
    Serial.println(F("ppm"));
    Serial.print(F("PM:"));
    Serial.print(sensor_dust25);
    Serial.println(F("ug/m3"));

    Serial.println(F("====================="));

    //啟動看門狗
    wdt_enable (WDTO_8S);
    Adafruit_CC3000_Client client = cc3000.connectTCP(ip, 80);
    if (client.connected()) {
      Serial.println(F("Connected to Thingspeak server."));
    } else {
      while (1) {}
    }
    wdt_reset ();
    Serial.println ("Sending data:"); //顯示上傳的數據
    //使用http get送出數據
    client.fastrprint(F("GET "));
    client.print(thingSpeakAddress);
    client.fastrprint(F("api_key="));
    client.print(writeAPIKey);
    wdt_reset ();
    client.fastrprint(F("&field1="));
    client.print(sensor_tem);
    client.fastrprint(F("&field2="));
    client.print(sensor_hum);
    wdt_reset ();
    client.fastrprint(F("&field3="));
    client.print(sensor_soil);
    client.fastrprint(F("&field4="));
    client.print(sensor_voc);
    wdt_reset ();
    client.fastrprint(F("&field5="));
    client.print(sensor_dust25);
    client.fastrprint(F("\r\n"));
    wdt_reset ();
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

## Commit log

2015-09-05 fritzing sketch upload
    [ProbeCube_nano_v1.fzz, ProbePot_shield.fzz]
2015-09-05 fzz fig
    [ProbeCube_shield_v1.fzz]
2015-09-05 3d print part
    [ProbeCube_shiled_bumper_v1.stl]
2016-02-19 v0.98
    1. Change timer from delay to millis method make it more accurate.
    2. Change the DHCP waiting method.
2016-02-20 add fitzing
    [ProbeCube_gieger.fzz]
2016-02-23 split subproject
    [ProbeCube_gieger.fzz, ProbeCube_nano_v1.fzz, ProbeCube_shield_v1.fzz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]
2016-02-23 Create ProbeCube_pc_v1b0223
2016-02-23 Update ProbeCube_pc_v1b0223
2016-02-23 Update and rename ProbeCube_pc_v1b0223.ino to ProbeCube_pc_v099b0223.ino
2016-02-23 fzz update
    [ProbeCube_v099_20160223.fzz]
2016-02-29 for g3 sensor
2016-03-10 move folder
    [ProbeCube_gieger.fzz]
2016-03-11 add 3d print case file
    [pc099open_r4_base_fixed.stl, pc099open_r4_top_fixed.stl]
2016-03-19 add gerber
2016-03-28 revised 3d print model
    [pc100_base_r3_fixed.stl, pc100_top_r3_fixed_set.stl]
2016-04-03 add bom
2017-02-04 CH34 driver for OSX 10.11 and macOS 10.12
2017-02-04 Add CH341 driver for OSX 10.8 -10.10
2017-02-04 Add CH341 driver for OSX 10.11 and macOS 10.12
2017-02-13 Add set button on top
2017-04-07 Structure secure fix
    [pc100open_r2_base_fixed.stl, pc100open_r2_top_fixed.stl]

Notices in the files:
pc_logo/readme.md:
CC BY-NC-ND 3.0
